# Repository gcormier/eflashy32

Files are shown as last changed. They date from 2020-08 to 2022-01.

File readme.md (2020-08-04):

# eflashy32
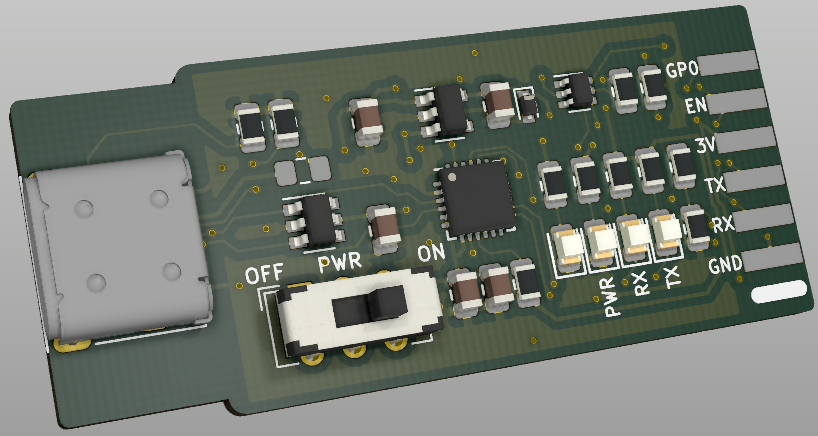
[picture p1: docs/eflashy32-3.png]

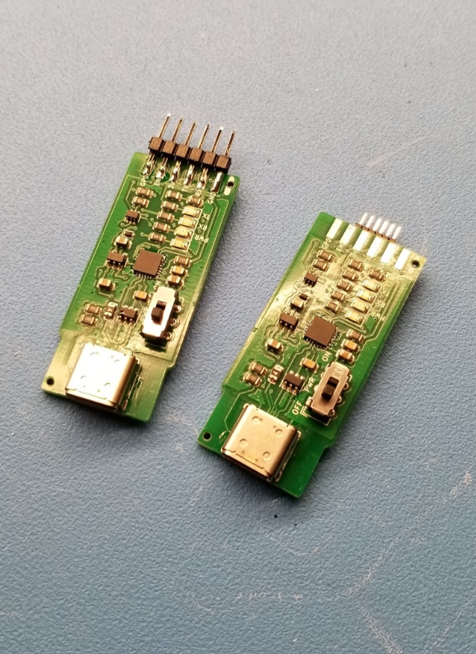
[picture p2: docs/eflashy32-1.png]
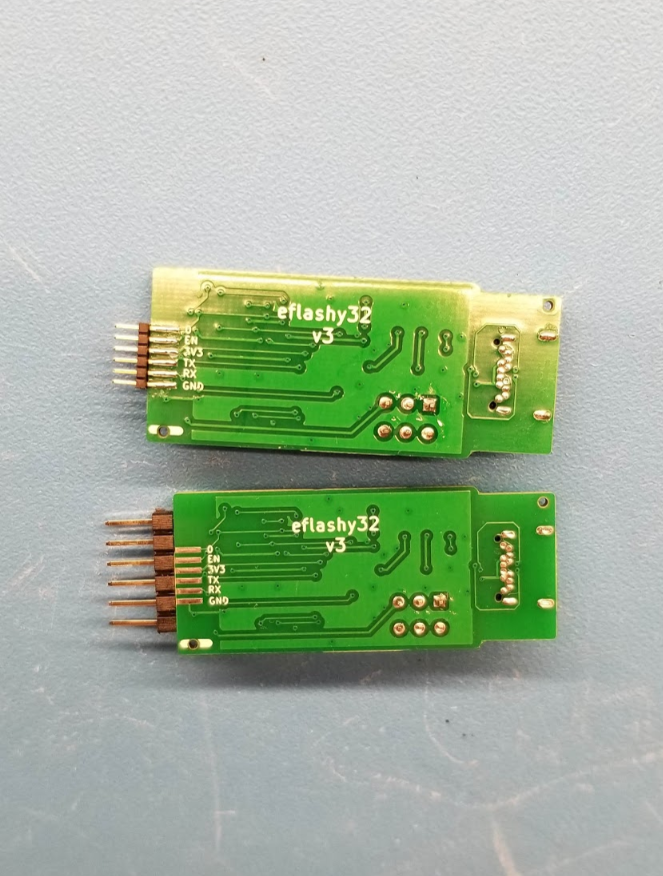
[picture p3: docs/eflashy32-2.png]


eflashy32 is a USB Type-C, CP2102N serial interface targeting ESP devices. It has a 500mA resettable fuse, ESD protection, and a switch to choose if you want to send 3.3V to the device or not.

While Micro USB is still everywhere, USB-C needs to start taking over. My new laptop has only USB-C ports, and I wanted to have one less dongle.

The board is designed in a such a manner to allow either a 2.54mm pitch 1x6 pin header, 1.27mm pitch header, or pogo pins!

## Tindie
Available <a href="https://www.tindie.com/products/gcormier/eflashy32/">for purchase on Tindie</a>.

## Design Goals
- [ ] USB Type C
- [ ] Good serial chip with no drivers needed and no <a href="https://hackaday.com/2016/02/01/ftdi-drivers-break-fake-chips-again/">malware</a>
- [ ] Switch to toggle providing power to device
- [ ] Small
- [ ] Ability to use pogo pins

## Notes
I added the ubiquitous 2.54mm pitch header for classic scenarios, using either a 6 pin header, or using 6 pogo pins. On the back side is a similar 1.27mm pitch header for miniature designs.

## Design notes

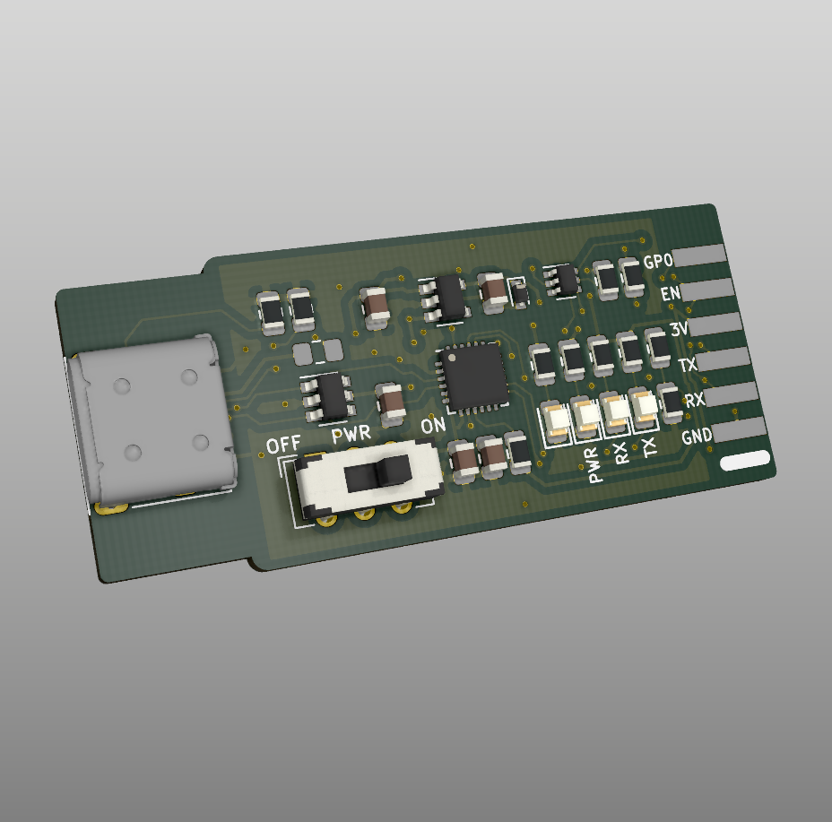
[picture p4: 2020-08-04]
docs/eflashy32-4.png

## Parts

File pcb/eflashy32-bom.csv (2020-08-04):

Comment | Designator | Footprint | LCSC
1uF/10V | C1 | Capacitor_SMD:C_0805_2012Metric | C28323
0.1uF/10V | C2,C9 | Capacitor_SMD:C_0805_2012Metric | C49678
4.7uF/6V | C5,C6 | Capacitor_SMD:C_0805_2012Metric | C1779
RX | D1 | LED_SMD:LED_0805_2012Metric | C2293
TX | D2 | LED_SMD:LED_0805_2012Metric | C2293
VBUS | D3 | LED_SMD:LED_0805_2012Metric | C2297
PWR | D4 | LED_SMD:LED_0805_2012Metric | C84256
ESD5Z3.3T1G | D5 | Diode_SMD:D_SOD-523 | C61148
0ZCK0050FF2E (TLC-PSMD050) | F2 | Fuse:Fuse_0805_2012Metric_Pad1.15x1.40mm_HandSolder | C261942
SERIAL | J1 | !Greg:2.54mmedge | DNP
10137062-00021LF | J2 | !Greg:USBC-Amphenol-10137062-00021LF | DNP
SERIAL2 | J3 | !Greg:1.27mmedge | DNP
MMDT3904 | Q1 | Package_TO_SOT_SMD:SOT-363_SC-70-6 | C83572
22k1 | R15 | Resistor_SMD:R_0805_2012Metric | C17560
47k5 | R16 | Resistor_SMD:R_0805_2012Metric | C17713
5k1 | R6,R7,R17 | Resistor_SMD:R_0805_2012Metric | C17513
1k | R1,R2,R3,R18 | Resistor_SMD:R_0805_2012Metric | C17414
10k | R4,R5 | Resistor_SMD:R_0805_2012Metric | C27834
JS202011CQN | SW1 | Button_Switch_THT:SW_CuK_JS202011CQN_DPDT_Straight | DNP
ESD PROTECTION | U1 | Package_TO_SOT_SMD:SOT-23-6 | C294963
CP2102N-A02-GQFN24 | U2 | Package_DFN_QFN:QFN-24-1EP_4x4mm_P0.5mm_EP2.6x2.6mm | ???
TLV75533PDBV | U3 | Package_TO_SOT_SMD:SOT-23-5 | C255621 C404027

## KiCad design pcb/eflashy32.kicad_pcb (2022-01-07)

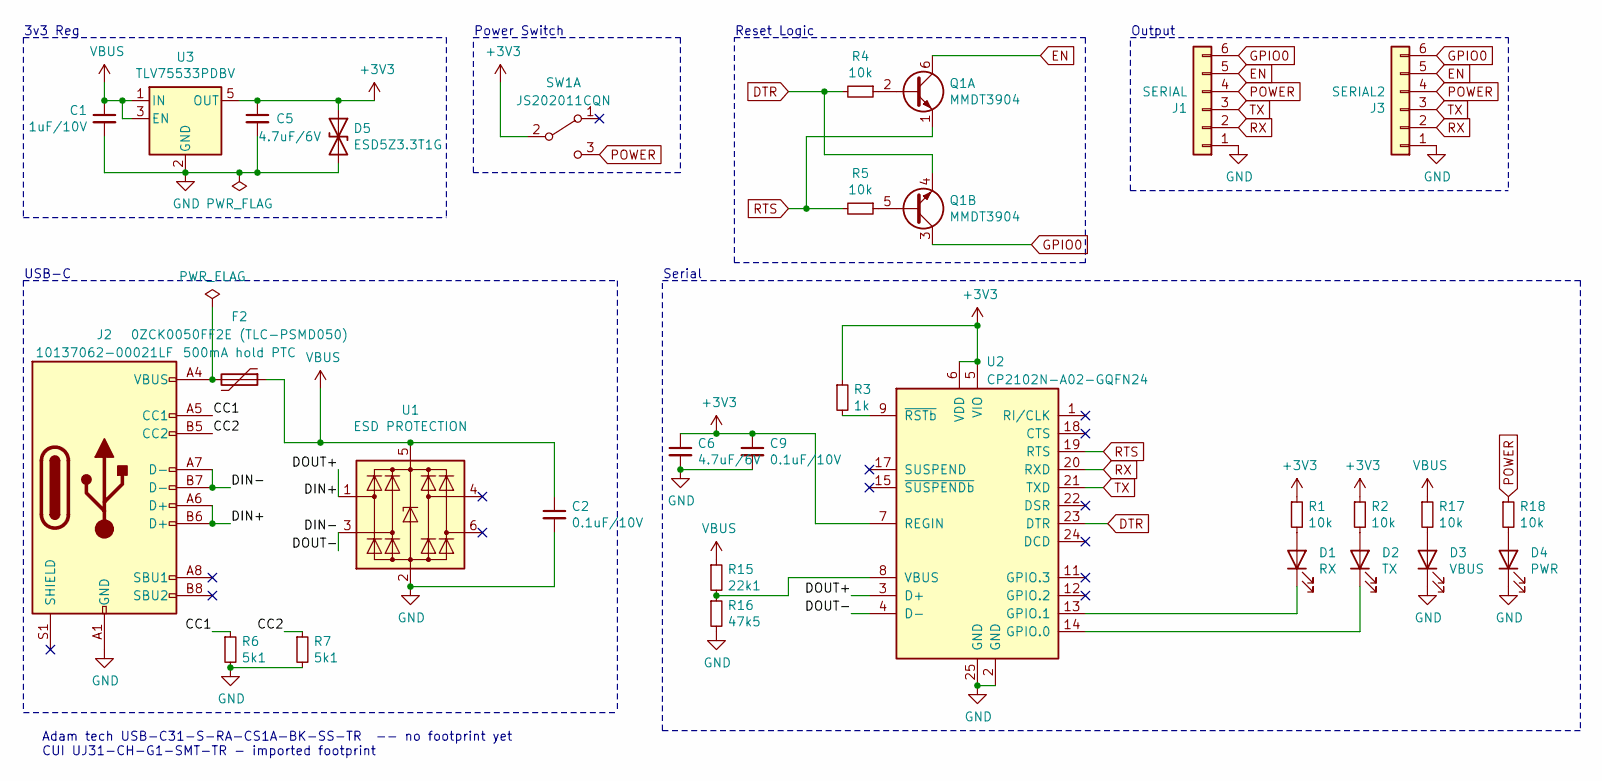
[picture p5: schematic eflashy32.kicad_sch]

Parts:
C1: 1uF/10V; C_0805_2012Metric; LCSC C28323
C2, C9: 0.1uF/10V; C_0805_2012Metric; LCSC C49678
C5, C6: 4.7uF/6V; C_0805_2012Metric; LCSC C1779
D1: RX; LED_0805_2012Metric; LCSC C2293
D2: TX; LED_0805_2012Metric; LCSC C2293
D3: VBUS; LED_0805_2012Metric; LCSC C2297
D4: PWR; LED_0805_2012Metric; LCSC C84256
D5: ESD5Z3.3T1G; D_SOD-523; LCSC C61148
F2: 0ZCK0050FF2E (TLC-PSMD050); Fuse_0805_2012Metric_Pad1.15x1.40mm_HandSolder; LCSC C261942
J1: SERIAL; 2.54mmedge; LCSC DNP
J2: 10137062-00021LF; USBC-Amphenol-10137062-00021LF; LCSC C388659
J3: SERIAL2; 1.27mmedge; LCSC DNP
Q1: MMDT3904; SOT-363_SC-70-6; LCSC C83572
R1, R2, R4, R5, R17, R18: 10k; R_0805_2012Metric; LCSC C17414
R3: 1k; R_0805_2012Metric; LCSC C17513
R6, R7: 5k1; R_0805_2012Metric; LCSC C27834
R15: 22k1; R_0805_2012Metric; LCSC C17560
R16: 47k5; R_0805_2012Metric; LCSC C17713
SW1: JS202011CQN; SW_CuK_JS202011CQN_DPDT_Straight; LCSC DNP
U1: ESD PROTECTION; SOT-23-6; LCSC C294963
U2: CP2102N-A02-GQFN24; QFN-24-1EP_4x4mm_P0.5mm_EP2.6x2.6mm; LCSC C969151
U3: TLV75533PDBV; SOT-23-5; LCSC C255621 C404027

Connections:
+3V3: C5.1, C6.1, C9.1, D5.1 (A1), R1.1, R2.1, R3.1, SW1.2 (B), U2.5 (VIO), U2.6 (VDD), U2.7 (REGIN), U3.5 (OUT)
/CC1: J2.A5 (CC1), R6.1
/CC2: J2.B5 (CC2), R7.1
/DIN+: J2.A6 (D+), J2.B6 (D+), U1.1 (I/O1), U2.3 (D+)
/DIN-: J2.A7 (D-), J2.B7 (D-), U1.3 (I/O2), U2.4 (D-)
DTR: Q1.4 (E2), R4.2, U2.23 (DTR)
EN: J1.5, J3.5, Q1.6 (C1)
GND: C1.2, C2.2, C5.2, C6.2, C9.2, D3.1 (K), D4.1 (K), D5.2 (A2), J1.1, J2.A1 (GND), J2.A12 (GND), J2.B1 (GND), J2.B12 (GND), J3.1, R6.2, R7.2, R16.2, U1.2 (GND), U2.2 (GND), U2.25 (GND), U3.2 (GND)
GPIO0: J1.6, J3.6, Q1.3 (C2)
unnamed: D1.1 (K), U2.13 (GPIO.1)
unnamed: D1.2 (A), R1.2
unnamed: D2.1 (K), U2.14 (GPIO.0)
unnamed: D2.2 (A), R2.2
unnamed: D3.2 (A), R17.2
unnamed: D4.2 (A), R18.2
unnamed: F2.2, J2.A4 (VBUS), J2.A9 (VBUS), J2.B4 (VBUS), J2.B9 (VBUS)
unnamed: Q1.2 (B1), R4.1
unnamed: Q1.5 (B2), R5.1
unnamed: R3.2, U2.9 (~RSTb)
unnamed: R15.2, R16.1, U2.8 (VBUS)
POWER: J1.4, J3.4, R18.1, SW1.3 (C)
RTS: Q1.1 (E1), R5.2, U2.19 (RTS)
RX: J1.2, J3.2, U2.20 (RXD)
TX: J1.3, J3.3, U2.21 (TXD)
VBUS: C1.1, C2.1, F2.1, R15.1, R17.1, U1.5 (VBUS), U3.1 (IN), U3.3 (EN)

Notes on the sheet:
3v3 Reg
USB-C
Adam tech USB-C31-S-RA-CS1A-BK-SS-TR -- no footprint yet CUI UJ31-CH-G1-SMT-TR - imported footprint
Power Switch
Serial
Reset Logic
Output

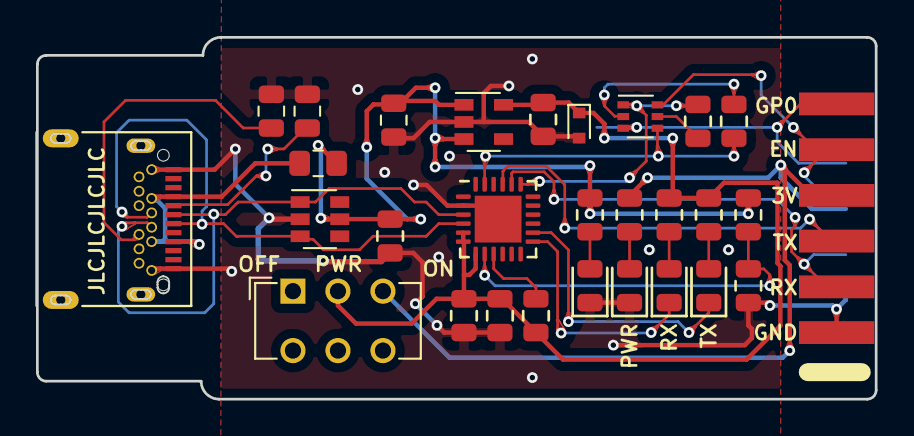
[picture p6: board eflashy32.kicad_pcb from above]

Board: 2 copper layers, 46.6 x 20.1 mm, 30 parts (1 on the bottom side), 25 nets.

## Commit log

2020-07-22 software for bulk changes to cp2102n
    [eflashy32.kicad_pcb, eflashy32.sch]
2020-07-22 don't ignore bom
2020-07-23 updated bom with lcsc for jellybeans
    [eflashy32-bom.csv]
2020-07-23 change to 4 line
    [eflashy32-B_Mask.gbr, eflashy32-B_Paste.gbr, eflashy32-B_SilkS.gbr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]
